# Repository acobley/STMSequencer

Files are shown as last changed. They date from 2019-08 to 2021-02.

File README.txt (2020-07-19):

Production board was :
StmPulse-V1-G49804

*Note* the design has a fault.  R2 and R5 are attached to 5V but should be attached to +5V

I added an airwire to link them on my build.

*NOTE*  the trigger output on board StmPulse-V1-G49804 was only 3.3V whihc is not enough to trigger some modules.

*StmPulse-V2-InProgress.sch*
This fixes the above faults, it connects R2 and R5 to +5V and adds output transistors on the gates to give 5V.

StmPulse-V2-InProgress has *NOT* been built or tested.

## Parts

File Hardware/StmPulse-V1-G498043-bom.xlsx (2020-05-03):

Library | Qty | Parts | Description | Value | Package | LABEL | LABLEL | MPN | Status | OC_FARNELL | OC_NEWARK | PACKAGE | PROD_ID | RS-PART | SF_SKU | SUPPLIER
INSTRUO | 1 | BUT3 |  | PB6149L-5 | PB6149L |  |  |  | y
rcl | 4 | C1, C2, C15, C16 | CAPACITOR, American symbol | 10nF | C0805 |  |  |  | Y 8
rcl | 3 | C3, C5, C8 | CAPACITOR, American symbol | 100n | C0805K |  |  |  | Y
GMSN | 2 | C4, C7 | POLARIZED CAPACITOR, American symbol | 10u | 153CLV-0505 |  |  |  | Y
rcl | 1 | C6 | CAPACITOR, American symbol | 10u | C0805K |  |  |  | Y |  |  |  |  | 737-9704
INSTRUO | 10 | CV1, CV2, CV3, CV4, RESET, START, TRIG1, TRIG2, TRIG3, TRIG4 |  | S_JACK | S_JACK |  |  |  | Y 10
GMSN | 1 | D1 | Diode | Stth102a | SMADIODE |  |  |  | y
Adafruit_1.3_128x64_OLED | 1 | DISPLAY | PIN HEADER |  | MICROBUILDER_1X08_ROUND |  |  |  | Y
GMSN | 1 | IC1 | Positive VOLTAGE REGULATOR | 78M05 | TO252 |  |  |  | Y
GMSN-R2Project | 1 | IC2 | OP AMP | MCP6004D | SO14 |  |  |  | Y
SparkFun-Connectors | 1 | POWER | Multi connection point. Often used as Generic Header-pin footprint for 0.1 inch spaced/style header connections |  | 2X5-SHROUDED_SMD |  |  |  | Y |  |  |  | CONN-09508 | 828-1783
SparkFun-Connectors | 1 | PROGRAM | Multi connection point. Often used as Generic Header-pin footprint for 0.1 inch spaced/style header connections | Program | 1X06 |  |  |  | Y |  |  |  | CONN-08437
rcl | 17 | R1, R2, R3, R4, R5, R6, R7, R8, R9, R10, R11, R12, R15, R18, R21, R22, R24 | RESISTOR, American symbol | 10K | R0805 |  |  |  | n 14 |  |  |  |  | 223-0562 / 125-1189
rcl | 1 | R13 | RESISTOR, American symbol | 2K | R0805 |  |  |  | N |  |  |  |  | 812-3508
rcl | 1 | R14 | RESISTOR, American symbol | 220R | R0805 |  |  |  | Y
rcl | 3 | R16, R19, R23 | RESISTOR, American symbol | 100K | R0805 |  |  |  | Y 8
rcl | 2 | R17, R20 | RESISTOR, American symbol | 1M | R0805 |  |  |  | N |  |  |  |  | 223-0821
GMSN-R2Project | 1 | REF | PRECISION MICROPOWER SHUNT VOLTAGE REFERENCE | LM4040 | SOT95P237X112-3N |  |  | LM4040A30IDBZT | y 1 | 1755108 | 58K5870 | 3-SOT-23 |  | 809-6343 |  | TEXAS INSTRUMENTS
SparkFun-Switches | 2 | S1, S2 | Rotary Encoder w/ Select Switch | ENCODER-SWITCH | ROTARY_ENC_PLAIN |  |  |  | Y 2 |  |  |  |  |  | COM-09117
INSTRUO | 1 | T1_CLOCK |  | 2N3904 | TRANSISTOR_SINGLE_N-TYPE |  | T1_Start |  | y |  |  |  |  | 725-8616
INSTRUO | 1 | T2_RESET |  | TRANSISTOR_MMBT3904 | TRANSISTOR_SINGLE_N-TYPE | T2_Reset |  |  | y |  |  |  |  | 725-8616
BluePill | 1 | U$1 |  | Blue Pill | BLUE_PILL |  |  |  | Y
GMSN-R2Project | 1 | U1 | OP AMP | MCP6004D | SO14 |  |  |  | Y |  |  |  |  | 628-3481 (10)
GMSN-R2Project | 1 | U2-MCP4922 |  | MCP4922MCP4922-SO14 | SO14 |  |  |  | Old |  |  |  |  | 402-910

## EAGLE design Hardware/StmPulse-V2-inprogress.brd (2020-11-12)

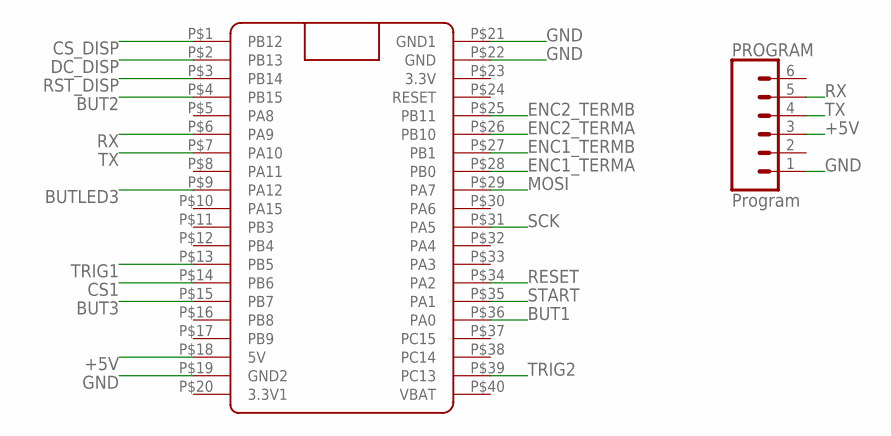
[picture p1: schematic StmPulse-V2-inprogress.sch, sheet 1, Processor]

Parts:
PROGRAM: Program; 1X06
U$1: Blue Pill; BLUE_PILL

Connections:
+5V: PROGRAM.3, U$1.P$18 (5V); also elsewhere on the board
BUT1: U$1.P$36 (PA0); also elsewhere on the board
BUT2: U$1.P$4 (PB15); also elsewhere on the board
BUT3: U$1.P$15 (PB7); also elsewhere on the board
BUTLED3: U$1.P$9 (PA12); also elsewhere on the board
CS1: U$1.P$14 (PB6); also elsewhere on the board
CS_DISP: U$1.P$1 (PB12); also elsewhere on the board
DC_DISP: U$1.P$2 (PB13); also elsewhere on the board
ENC1_TERMA: U$1.P$28 (PB0); also elsewhere on the board
ENC1_TERMB: U$1.P$27 (PB1); also elsewhere on the board
ENC2_TERMA: U$1.P$26 (PB10); also elsewhere on the board
ENC2_TERMB: U$1.P$25 (PB11); also elsewhere on the board
GND: PROGRAM.1, U$1.P$19 (GND2), U$1.P$21 (GND1), U$1.P$22 (GND); also elsewhere on the board
MOSI: U$1.P$29 (PA7); also elsewhere on the board
RESET: U$1.P$34 (PA2); also elsewhere on the board
RST_DISP: U$1.P$3 (PB14); also elsewhere on the board
RX: PROGRAM.5, U$1.P$6 (PA9)
SCK: U$1.P$31 (PA5); also elsewhere on the board
START: U$1.P$35 (PA1); also elsewhere on the board
TRIG1: U$1.P$13 (PB5); also elsewhere on the board
TRIG2: U$1.P$39 (PC13); also elsewhere on the board
TX: PROGRAM.4, U$1.P$7 (PA10)

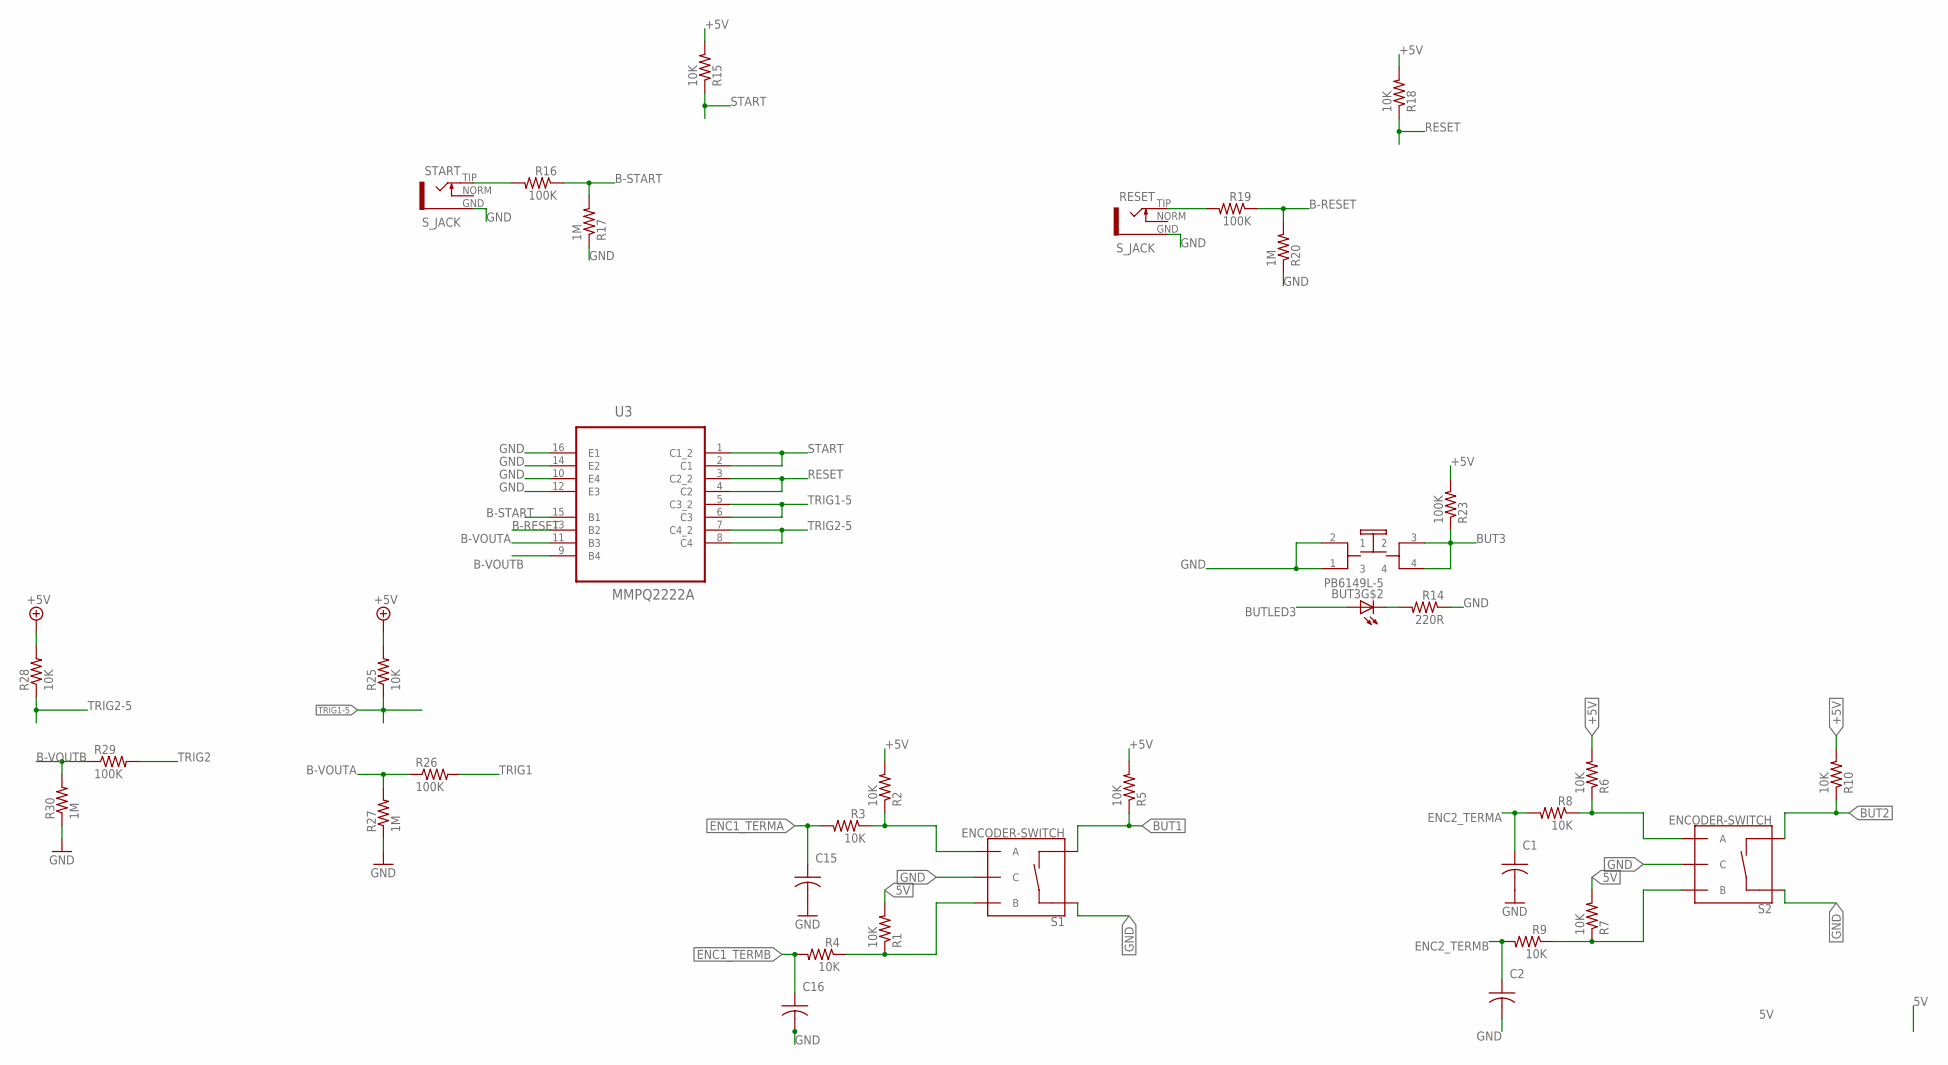
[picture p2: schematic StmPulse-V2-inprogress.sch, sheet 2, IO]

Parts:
BUT3: PB6149L-5; PB6149L
C1, C2, C15, C16: 10nF; C0805
R1, R2, R3, R4, R5, R6, R7, R8, R9, R10, R15, R18, R25, R28: 10K; R0805
R14: 220R; R0805
R16, R19, R23, R26, R29: 100K; R0805
R17, R20, R27, R30: 1M; R0805
RESET: S_JACK
S1, S2: ENCODER-SWITCH; ROTARY_ENC_PLAIN
START: S_JACK
U3: MMPQ2222A; SOIC127P600X175-16N

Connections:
5V: R1.2, R7.2
+5V: R2.2, R5.2, R6.2, R10.2, R15.2, R18.2, R23.2, R25.2, R28.2; also elsewhere on the board
B-RESET: R19.1, R20.2, U3.13 (B2)
B-START: R16.1, R17.2, U3.15 (B1)
B-VOUTA: R26.1, R27.2, U3.11 (B3)
B-VOUTB: R29.1, R30.2, U3.9 (B4)
BUT1: R5.1, S1.SW-; also elsewhere on the board
BUT2: R10.1, S2.SW-; also elsewhere on the board
BUT3: BUT3.3 (2), BUT3.4, R23.1; also elsewhere on the board
BUTLED3: BUT3.A; also elsewhere on the board
ENC1_TERMA: C15.1, R3.2; also elsewhere on the board
ENC1_TERMB: C16.1, R4.2; also elsewhere on the board
ENC2_TERMA: C1.1, R8.2; also elsewhere on the board
ENC2_TERMB: C2.1, R9.2; also elsewhere on the board
GND: BUT3.1 (3), BUT3.2 (1), C1.2, C2.2, C15.2, C16.2, R14.1, R17.1, R20.1, R27.1, R30.1, RESET.GND, S1.C, S1.SW+, S2.C, S2.SW+, START.GND, U3.10 (E4), U3.12 (E3), U3.14 (E2), U3.16 (E1); also elsewhere on the board
unnamed: R6.1, R8.1, S2.A
unnamed: R7.1, R9.1, S2.B
unnamed: R2.1, R3.1, S1.A
unnamed: R1.1, R4.1, S1.B
unnamed: BUT3.K (C), R14.2
unnamed: R19.2, RESET.TIP
unnamed: R16.2, START.TIP
RESET: R18.1, U3.3 (C2_2), U3.4 (C2); also elsewhere on the board
START: R15.1, U3.1 (C1_2), U3.2 (C1); also elsewhere on the board
TRIG1: R26.2; also elsewhere on the board
TRIG1-5: R25.1, U3.5 (C3_2), U3.6 (C3); also elsewhere on the board
TRIG2: R29.2; also elsewhere on the board
TRIG2-5: R28.1, U3.7 (C4_2), U3.8 (C4); also elsewhere on the board

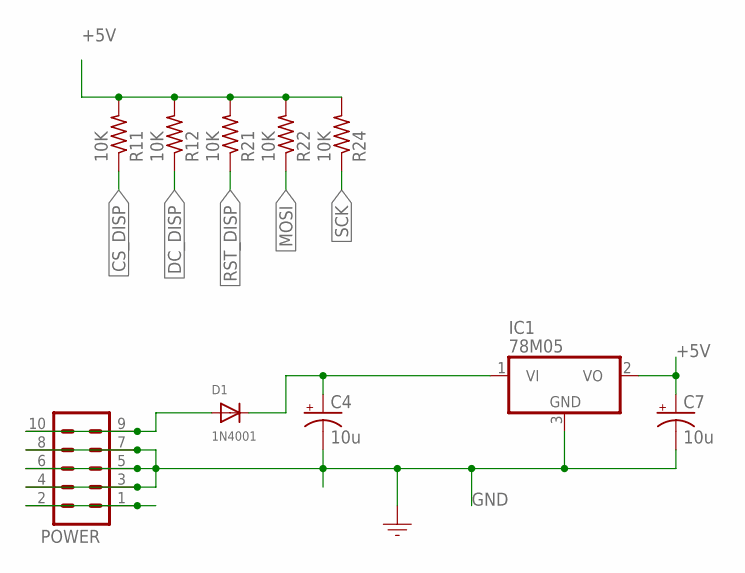
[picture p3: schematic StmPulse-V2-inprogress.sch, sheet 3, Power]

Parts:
C4, C7: 10u; 153CLV-0505
D1: 1N4001; SMADIODE
IC1: 78M05; TO252
POWER: CONN_05X2SHD_SMD; 2X5-SHROUDED_SMD
R11, R12, R21, R22, R24: 10K; R0805

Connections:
+5V: C7.+, IC1.2 (VO), R11.2, R12.2, R21.2, R22.2, R24.2; also elsewhere on the board
+12V: C4.+, D1.C, IC1.1 (VI)
CS_DISP: R11.1; also elsewhere on the board
DC_DISP: R12.1; also elsewhere on the board
GND: C4.-, C7.-, IC1.3 (GND), POWER.3, POWER.4, POWER.5, POWER.6, POWER.7, POWER.8; also elsewhere on the board
MOSI: R22.1; also elsewhere on the board
unnamed: D1.A, POWER.9, POWER.10
unnamed: POWER.1, POWER.2
RST_DISP: R21.1; also elsewhere on the board
SCK: R24.1; also elsewhere on the board

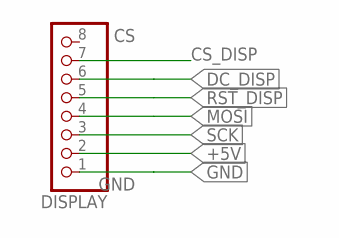
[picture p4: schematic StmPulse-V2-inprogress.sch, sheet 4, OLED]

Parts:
DISPLAY: MICROBUILDER_HEADER-1X8ROUND; MICROBUILDER_1X08_ROUND

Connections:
+5V: DISPLAY.2; also elsewhere on the board
CS_DISP: DISPLAY.7; also elsewhere on the board
DC_DISP: DISPLAY.6; also elsewhere on the board
GND: DISPLAY.1; also elsewhere on the board
MOSI: DISPLAY.4; also elsewhere on the board
RST_DISP: DISPLAY.5; also elsewhere on the board
SCK: DISPLAY.3; also elsewhere on the board

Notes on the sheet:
GND

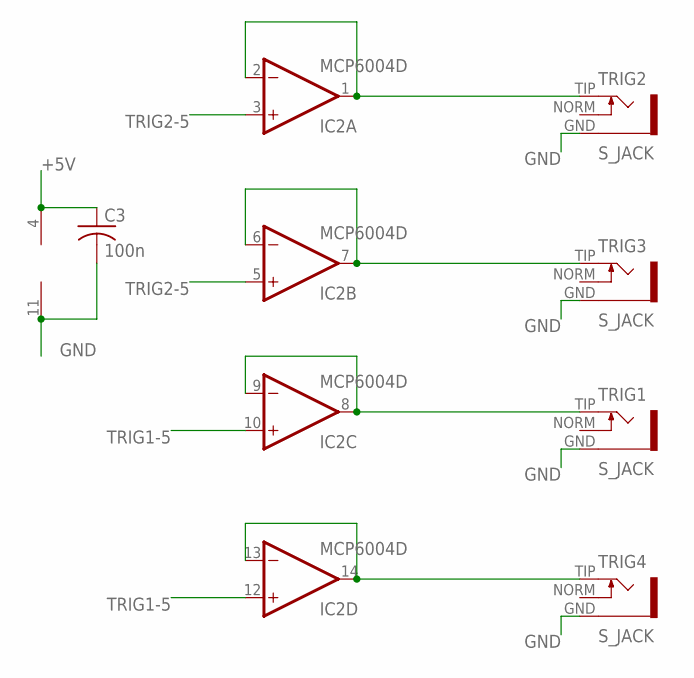
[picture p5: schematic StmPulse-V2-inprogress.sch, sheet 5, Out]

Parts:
C3: 100n; C0805K
IC2: MCP6004D; SO14
TRIG1, TRIG2, TRIG3, TRIG4: S_JACK

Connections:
+5V: C3.1, IC2.4 (V+); also elsewhere on the board
GND: C3.2, IC2.11 (V-), TRIG1.GND, TRIG2.GND, TRIG3.GND, TRIG4.GND; also elsewhere on the board
unnamed: IC2.1 (OUT), IC2.2 (-IN), TRIG2.TIP
unnamed: IC2.8 (OUT), IC2.9 (-IN), TRIG1.TIP
unnamed: IC2.6 (-IN), IC2.7 (OUT), TRIG3.TIP
unnamed: IC2.13 (-IN), IC2.14 (OUT), TRIG4.TIP
TRIG1-5: IC2.10 (+IN), IC2.12 (+IN); also elsewhere on the board
TRIG2-5: IC2.3 (+IN), IC2.5 (+IN); also elsewhere on the board

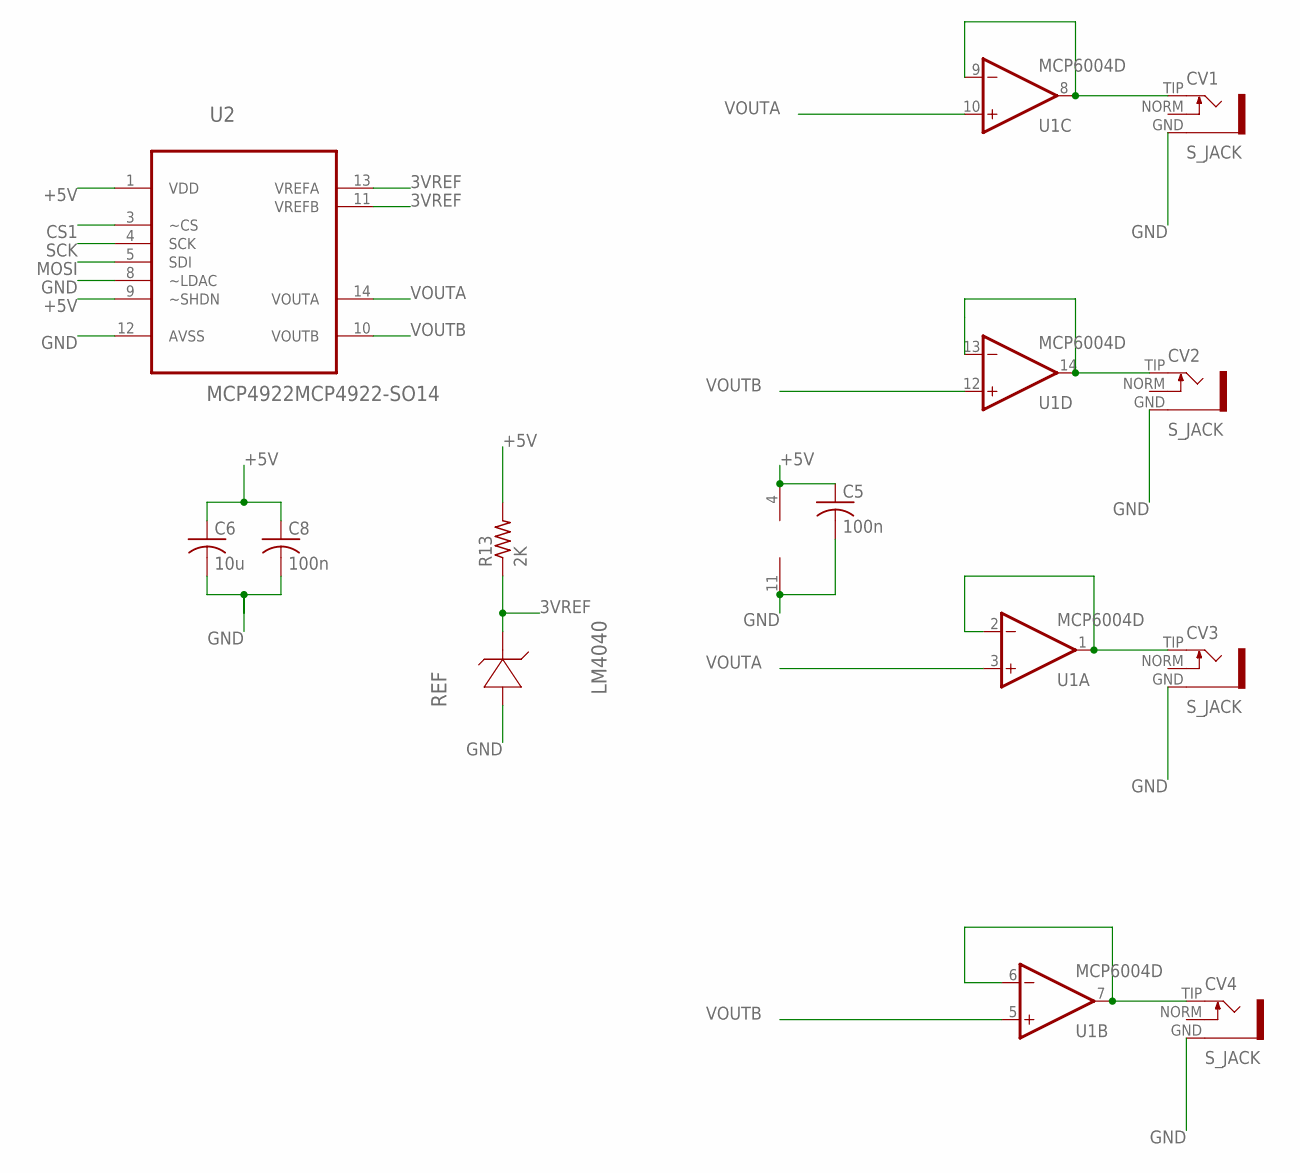
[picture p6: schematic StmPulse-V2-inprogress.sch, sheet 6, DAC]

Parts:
C5, C8: 100n; C0805K
C6: 10u; C0805K
CV1, CV2, CV3, CV4: S_JACK
R13: 2K; R0805
REF: LM4040; SOT95P237X112-3N; MPN LM4040A30IDBZT
U1: MCP6004D; SO14
U2: MCP4922MCP4922-SO14; SO14

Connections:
3VREF: R13.1, REF.1 (CATHODE), U2.11 (VREFB), U2.13 (VREFA)
+5V: C5.1, C6.1, C8.1, R13.2, U1.4 (V+), U2.1 (VDD), U2.9 (~SHDN); also elsewhere on the board
CS1: U2.3 (~CS); also elsewhere on the board
GND: C5.2, C6.2, C8.2, CV1.GND, CV2.GND, CV3.GND, CV4.GND, REF.2 (ANODE), U1.11 (V-), U2.8 (~LDAC), U2.12 (AVSS); also elsewhere on the board
MOSI: U2.5 (SDI); also elsewhere on the board
unnamed: CV3.TIP, U1.1 (OUT), U1.2 (-IN)
unnamed: CV4.TIP, U1.6 (-IN), U1.7 (OUT)
unnamed: CV1.TIP, U1.8 (OUT), U1.9 (-IN)
unnamed: CV2.TIP, U1.13 (-IN), U1.14 (OUT)
SCK: U2.4 (SCK); also elsewhere on the board
VOUTA: U1.3 (+IN), U1.10 (+IN), U2.14 (VOUTA)
VOUTB: U1.5 (+IN), U1.12 (+IN), U2.10 (VOUTB)

Board: 2 copper layers, 68 parts (14 on the bottom side), 50 nets, no tracks yet.

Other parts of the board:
U$2, U$3, U$4, U$5: MOUNTING_HOLE

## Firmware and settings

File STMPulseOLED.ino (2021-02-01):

/*
   Contains code from HobbyComponents.com

   You may copy, alter and reuse this code in any way you like, but please leave
  reference to HobbyComponents.com in your comments if you redistribute this code.
  This software may not be used directly for the purpose of promoting products that
  directly compete with Hobby Components Ltd's own range of products.

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


*/

/*
    To setup BluePill:

    https://circuitdigest.com/microcontroller-projects/getting-started-with-stm32-development-board-stm32f103c8-using-arduino-ide

*/


#include "HardwareTimer.h"
#include "Setup.h"
/*
  void BeatsNumber() {
  float tmp = 0.0;
  int i = 0;
  for (i = 0; i < countlength; i++) {
    if (Timers[i] >= 3) {
      tmp = tmp  + 1.0 / (float)NoteLengths[Timers[i]];
    } else {
      if (Timers[i] == 1) {
        tmp = tmp  + 4;
      } else {
        if (Timers[i] == 2) {
          tmp = tmp  + 2;
        }
      }
    }
  }
  NumberOfBeats = tmp;
  }
*/

void BeatsNumber() {
  float tmp = 0.0;
  int i = 0;
  for (i = 0; i < countlength; i++) {

    tmp = tmp  +  (float)BeatLengths[Timers[i]];

  }
  NumberOfBeats = tmp;
}
#include "Display.h"
#include <EEPROM.h>



short PatternLengths[NumPatterns] = {13, 13, 4, 5, 4, 5, 4};
short NotePatterns [ NumPatterns][MaxPatternLength] = {

  {10, 8, 1, 3, 8, 5, 3, 8, 5, 1, 3, 10, 8},
  {10, 8, 1, 3, 8, 5, 3, 8, 5, 1, 3, 10, 8},
  {3, 3, 10, 1},
  {3, 3, 1, 10, 1},
  {10, 10, 5, 8},
  {10, 10, 8, 5, 8},
  {3, 3, 10, 1},
};
short TimerPatterns [ NumPatterns][MaxPatternLength] = {

  {3, 3, 3, 4, 4, 3, 4, 4, 3, 3, 3, 3, 3},
  {3, 4, 4, 4, 5, 5, 5, 5, 3, 3, 4, 3, 3},
  {3, 3, 3, 3},
  {2, 2, 2, 3, 3},
  {3, 3, 3, 3},
  {2, 2, 2, 3, 3},
  {1, 1, 1, 1},
};
short OctavePatterns [ NumPatterns][MaxPatternLength] = {

  {0, 0, 1, 1, 1, 1, 1, 1, 1, 1, 1, 0, 0},
  {0, 0, 1, 1, 1, 1, 1, 1, 1, 1, 1, 0, 0},
  {1, 1, 2, 2},
  {1, 1, 2, 2, 2},
  {1, 1, 2, 2},
  {1, 1, 2, 2, 2},
  {1, 1, 2, 2},
};
short TripletPatterns[ NumPatterns][MaxPatternLength] = {

  {0, 0, 0, 0, 0, 0, 0, 0, 0, 0, 0, 0, 0},
  {0, 0, 0, 0, 0, 0, 0, 0, 0, 0, 0, 0, 0},
  {0, 0, 0, 0},
  {0, 0, 0, 0, 0},
  {0, 0, 0, 0},
  {0, 0, 0, 0, 0},
  {0, 0, 0, 0},
};

short DottedPatterns[ NumPatterns][MaxPatternLength] = {

  {0, 0, 0, 0, 0, 0, 0, 0, 0, 0, 0, 0, 0},
  {0, 0, 0, 0, 0, 0, 0, 0, 0, 0, 0, 0, 0},
  {0, 0, 0, 0},
  {0, 0, 0, 0, 0},
  {0, 0, 0, 0},
  {0, 0, 0, 0, 0},
  {0, 0, 0, 0},
};

short VolumePatterns[ NumPatterns][MaxPatternLength] = {

  {0, 0, 1, 1, 1, 1, 1, 1, 1, 1, 1, 0, 0},
  {0, 0, 1, 1, 1, 1, 1, 1, 1, 1, 1, 0, 0},
  {1, 1, 1, 1},
  {1, 1, 1, 1, 1},
  {1, 1, 1, 1},
  {1, 1, 1, 1, 1},
  {1, 1, 1, 1},
};



//Low level routines to handle the timers.
//See https://www.st.com/content/ccc/resource/training/technical/product_training/c4/1b/56/83/3a/a1/47/64/STM32L4_WDG_TIMERS_GPTIM.pdf/files/STM32L4_WDG_TIMERS_GPTIM.pdf/j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
//Page 31 and 32

double Div = 1 / 72.0;
double PWM1 = 1;
double PWM2 = 1;
//This one used for Beat Timer
void CalcTCounters( long Time, HardwareTimer myTimer,PWMStruct *PWMS,long Pm1) {

  PWMS->PWM1=Pm1/50;
  PWMS->PWM2=(Time-Pm1)/50;
  DisplayTime(Time,3);
  DisplayTime(Pm1,4);
  DisplayTime(PWMS->PWM1,5);
  DisplayTime(PWMS->PWM2,6);



}

void SetUpTimer(ClockStruct *Clock,HardwareTimer myTimer, voidFuncPtr handler, timer_mode tm) {
  long Time=50L;
  myTimer.pause();
  myTimer.setMode(TIMER_CH1, tm);
  myTimer.attachInterrupt(TIMER_CH1, handler);
  Clock->Psc = 1;
  Clock->Arr = 0;
  Clock->Arr = Time/(Div*Clock->Psc);
  while (Clock->Arr >= 65535) {
    Clock->Psc = Clock->Psc + 1;
    Clock->Arr = Time/(Div*Clock->Psc);

  }
  myTimer.setPrescaleFactor(Clock->Psc);
  myTimer.setOverflow(Clock->Arr-1);
  myTimer.setCompare(TIMER_CH1,Clock->Arr-1);
  myTimer.refresh();

}


void SetupSwitches() {
  pinMode(BUT1, INPUT);
  pinMode(BUT2, INPUT);
  pinMode(STARTBUT, INPUT);
  pinMode(BUTLED3, OUTPUT);
  pinMode(START, INPUT);
  pinMode(RESET, INPUT);
  attachInterrupt(BUT1, iMode2, FALLING);
  attachInterrupt(BUT2, iMode, FALLING);
  attachInterrupt(STARTBUT, StartButtonInterrupt, FALLING);
  attachInterrupt(START, StartInterrupt, RISING);
  attachInterrupt(RESET, IntReset, RISING);

}

void SetupTimers() {
  //These set the timer modes to be correct for accurate timing
  // See http://docs.leaflabs.com/static.leaflabs.com/pub/leaflabs/maple-docs/latest/lang/api/hardwaretimer.html

  //SetUpTimer(SequenceTimer, SequenceGateOn, TIMER_OUTPUT_COMPARE);
  SetUpTimer(&MainClock,MainTimer, MasterClockInterrupt, TIMER_OUTPUT_COMPARE);
  setTempo(Tempo);  //Will also calculate timers.
  BeatPWMS.PWM1Counter=0;
  BeatPWMS.PWM2Counter=0;
  BeatPWMS.Phase=0;
  MainTimer.resume();

}

void MakeActivePattern(short Pattern) {
  int i = 0;
  CurrentPattern = Pattern;
  countlength = PatternLengths[Pattern];
  for (i = 0; i < MaxPatternLength; i++) {
    if (i < PatternLengths[Pattern]) {
      Notes[i] = NotePatterns[Pattern][i];
      Timers[i] = TimerPatterns[Pattern][i];
      Octave[i] = OctavePatterns[Pattern][i];
      Volume[i] = VolumePatterns[Pattern][i];
    }
  }
  CalculateBeatCountArray();
  BeatsNumber();

  DisplayBackground();
  DisplaySeqNum();

  DisplayTempo();
  DisplayMode();
  DisplayMode2();
  DisplayGateLength();


}




void CalculateBeatCountArray() {
  short TimerCount = 0;
  short BeatCount = 1;
  calcBeatPos[0] = 0;
  float CurrentBeatLength = 0;
  int countlength = PatternLengths[CurrentPattern];
  for (TimerCount = 1; TimerCount < countlength; TimerCount++) {

    CurrentBeatLength = CurrentBeatLength + (float)BeatLengths[Timers[TimerCount]];

    if ((CurrentBeatLength == (float)round(CurrentBeatLength))) {
      calcBeatPos[BeatCount] = TimerCount;
      BeatCount++;

    }
  }
  MaxBeat = BeatCount;
  for (int i = 0; i < BeatCount; i++) {
    BeatPos[i] = calcBeatPos[i];
  }
}



void setup() {
  //flash(5);
  SetupOLED();
  ReadEEPROM();
  SetupTimers();
  setTempo(Tempo);
  MakeActivePattern(CurrentPattern);
  SetupEncoders();
  SetupDacs();
  SetupSwitches();
  SetupGates();
  digitalWrite(BUTLED3, false);


}


void loop() {
  handleEnc1();
  handleEnc2();
}

boolean T1State = false;
void MasterClockInterrupt(){
  digitalWrite(Gate1, T1State);
  BeatGate();
  T1State = !T1State;
}

void StartAllTimers() {


  //SequenceGateOn();

}

boolean SequenceState = true;

int lastLength = NoteLengths[Timers[PlaceCount]];
void SequenceGateOn() {
  if (SequenceState == true) {
    digitalWrite(Gate1, true);
    //  Deal with notes
    WriteNote(Notes[PlaceCount], Octave[PlaceCount], CV1);

    // Display count
    DisplayCount(PlaceCount + 1, 0, 0);

    long Time = (long)(BaseTime / NoteLengths[Timers[PlaceCount]]);
    //DisplayCount(NoteLengths[Timers[PlaceCount]], 3,0);
    SeqGateTime = (long)((double)Time * ((double)GateLength / 8.0));
    CalcTCounters(Time, MainTimer,  &SequencePWMS, SeqGateTime);
    lastLength = NoteLengths[Timers[PlaceCount]];

    //Display Cursor

    Cursor(9 * PlaceCount, 12);
    DrawMode(INVERT);
    _WriteChar(BLOCK);

    if (ErasePos >= 0) {

      Cursor(9 * ErasePos, 12);
      DrawMode(INVERT);
      _WriteChar(BLOCK);
    }

    Refresh();
    ErasePos++;
    if (ErasePos >= countlength)
      ErasePos = 0;
    PlaceCount++;
    if (PlaceCount >= countlength) {
      PlaceCount = 0;
      ErasePos = countlength - 1;
      if ((NextPattern >= 0) && (NextPattern < 50)) {
        MakeActivePattern(NextPattern);
        DisplaySeqNum(CurrentPattern);
        NextPattern = -1;
      }
    }
  } else {
    digitalWrite(Gate1, false);

  }
  SequenceState = !SequenceState;
}

boolean BeatState = false;
boolean BeatDispDivisor = false;


void BeatGate(void) {
if (BeatPWMS.Phase==0){ //first phase;
   digitalWrite(BUTLED3, HIGH);
     digitalWrite(Gate2,HIGH);
     BeatPWMS.PWM1Counter++;
     if (BeatPWMS.PWM1Counter>BeatPWMS.PWM1){
        BeatPWMS.Phase=1;
        BeatPWMS.PWM2Counter=1;
        digitalWrite(Gate2,LOW);
     }
  }else{
     digitalWrite(BUTLED3, LOW);
     digitalWrite(Gate2,LOW);
     BeatPWMS.PWM2Counter++;
     if (BeatPWMS.PWM2Counter>BeatPWMS.PWM2){
        BeatPWMS.Phase=0;
        digitalWrite(Gate2,HIGH);
        BeatPWMS.PWM1Counter=1;
     }
  }

/*

  BeatTime = 1000000L * 60 / Tempo;

  if (BeatState == true) {


    digitalWrite(Gate2, HIGH);

    if  (BeatDispDivisor != false) { //The Beat clock runs at 2* for Volcas
      digitalWrite(BUTLED3, HIGH);
      DisplayCount(Beat, 14, 0);
      Cursor(9 * BeatPos[Beat - 1], 16);
      DrawMode(NORMAL);
      _WriteChar('_' - 32);
      bErasePos = Beat - 1;
      if (bErasePos <= 0)
        bErasePos = MaxBeat;
      Cursor(9 * BeatPos[bErasePos - 1], 16);
      DrawMode(CLEAR);
      _WriteChar('_' - 32);
      Refresh();
      Beat++;
      if (Beat > MaxBeat)
        Beat = 1;
    }
    BeatDispDivisor = !BeatDispDivisor;
  } else {
    digitalWrite(Gate2, LOW);

    digitalWrite(BUTLED3, LOW);

  }
  BeatState = !BeatState;

*/

}


boolean Running = false;
unsigned long TempoMicros = micros();
boolean Led = false;
unsigned long micro1 = 1000000;

void StartInterrupt() {
  StartButtonInterrupt();

}

void StartButtonInterrupt() {
  digitalWrite(BUTLED3, !digitalRead(BUTLED3));
  Running = !Running; //invert state

  if (Running) {
    Start();
  } else {
    Stop();
  }

}

void Start() {
  StartAllTimers();
}

void Stop() {
  digitalWrite(Gate1, false); //Avoid stuck notes
  digitalWrite(Gate2, false);
  digitalWrite(BUTLED3, false);
  /*
  SequenceTimer.setCount(0);
  SequenceTimer.pause();
  BeatTimer.setCount(0);
  BeatTimer.pause();
  */
  WriteEEProm();
}

void iMode() {
  Mode++;
  if (Mode > 4) {
    Mode = 0;

  }
  DisplayMode();
}

unsigned long currentMillis = millis();
unsigned long previousMillis = 0;
const long interval = 500;


int SencPos = CurrentPattern;

void iMode2() {
  noInterrupts();
  currentMillis = millis();
  //DisplayTime(currentMillis,previousMillis);
  if (currentMillis - previousMillis >= interval) {
    previousMillis = currentMillis;
    if (Mode2 == 1) {
      NextPattern = SencPos;
      //encPos = TencPos;
      DisplaySeqNum(NewEncPos);
      DisplayTempo();
      Mode2 = 0;

    } else { //From 0 to 1
      //TencPos=encPos;
      SencPos = CurrentPattern;
      Mode2 = 1;
    }
    DisplayMode2();
  }
  interrupts();
}




void handleEnc1() {
  switch (Mode2) {

    case 0:
      NewEncPos = encodeVal(Tempo);
      if (NewEncPos != Tempo) {
        if (NewEncPos < MinTempo) {
          NewEncPos = MinTempo;
        }
        if (NewEncPos > MaxTempo ) {
          NewEncPos = MaxTempo;
        }
        setTempo(NewEncPos);
      }
      break;
    case 1:
      NewEncPos = encodeVal(SencPos);
      if (NewEncPos != SencPos) {
        if (NewEncPos < 1) {
          NewEncPos = 0;
        }
        if (NewEncPos >= NumPatterns ) {
          NewEncPos = NumPatterns - 1;
        }
        DisplaySeqNum(NewEncPos);
        SencPos = NewEncPos; // will be set to next pattern when mode changes
      }
      break;
    default: break;
  }


}

int encodeVal(int val) {
  encAVal = digitalRead(encA);
  encBVal = digitalRead(encB);
  if (encAVal != encALast) {
    if (encAVal == encBVal) {
      val--;
    } else {
      val++;
    }
    encALast = encAVal;

  }
  return val;
}


void IntReset() {
  PlaceCount = 0;
}



void setTempo(int newTempo) {
  Tempo = newTempo;
  BaseTime = 1000000L * (4 * 60) / Tempo;
  BeatTime = 1000000L * 60 / Tempo;
  //DisplayTime (BeatTime );
  CalcTCounters(BeatTime / 2,  MainTimer, &BeatPWMS,(long)15000);
  //CalcTCounters(BaseTime, MainTimer, &SequencePWMS, SeqGateTime);
  DisplayTempo() ;
}



int encodeVal2(int val) {
  encAVal2 = digitalRead(enc2A);
  encBVal2 = digitalRead(enc2B);
  if (encAVal2 != encALast2) {
    if (encAVal2 == encBVal2) {
      val--;
    } else {
      val++;
    }
    encALast2 = encAVal2;

  }
  return val;
}





void handleEnc2() {

  NewEncPos2 = encodeVal2(encPos2);
  if (NewEncPos2 != encPos2) {
    switch (Mode) {
      case 0:
        encPos2 = NewEncPos2;
        if (encPos2 < 1) {
          encPos2 = 1;
        }
        if (encPos2 > 8 ) {
          encPos2 = 8;
        }
        GateLength = encPos2;
        //SeqGateTime = Time * (GateLength / 8);
        //CalcTPeriod(&SequenceClock, BaseTime, SequenceTimer, &SequencePWMS, SeqGateTime);
        DisplayGateLength() ;
        break;
      default: break;
    }
  }
}







void mcpWrite(int value, int Channel) {
  //CS
  noInterrupts();
  digitalWrite(DAC, LOW);
  //DAC1 write
  //set top 4 bits of value integer to data variable
  byte data = value >> 8;
  data = data & B00001111;
  if (Channel == 0)
    data = data | B00110000; //DACA Bit 15 Low
  else
    data = data | B10110000; //DACB Bit 15 High
  SPI.transfer(data);
  data = value;
  SPI.transfer(data);
  // Set digital pin DACCS HIGH
  digitalWrite(DAC, HIGH);
  interrupts();

}

void WriteNote(int Note, int Octave, int Channel) {
  hOctave = Octave;
  hNote = (byte)(Note % 12);
  houtValue = (int)(Range * (hOctave + (float)hNote / 12));
  mcpWrite(houtValue, Channel);

}


void ReadEEPROM() {
  int addr = 0;
  Tempo = EEPROM.read(addr);
  if ((Tempo < 10) || (Tempo > 300))
    Tempo = DefaultTempo;
  setTempo(Tempo);
  addr = addr + 1;
  GateLength = EEPROM.read(addr);
  if (GateLength < 1)
    GateLength = 4;
  if (GateLength > 8)
    GateLength = 4;
  addr = addr + 1;
  CurrentPattern = EEPROM.read(addr);
  if (CurrentPattern < 0)
    CurrentPattern = 2;
  if (CurrentPattern >= NumPatterns)
    CurrentPattern = NumPatterns - 1;
  encPos = Tempo;
  NewEncPos = Tempo;
  encPos2 = GateLength;
  NewEncPos2 = GateLength;
}

void WriteEEProm() {
  int addr = 0;
  EEPROM.write(addr, Tempo);
  addr = addr + 1;
  EEPROM.write(addr, GateLength);
  addr = addr + 1;
  EEPROM.write(addr, CurrentPattern);
}

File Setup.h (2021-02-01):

#include "SPI.h"
#include "fonts.h"


//Encoder
#define encA PB0
#define encB PB1

#define enc2A PB10 //11
#define enc2B PB11 //10
#define BUT1 PA0
#define BUT2 PB15
#define STARTBUT PB7
#define BUTLED3 PA12
#define START PA2
#define RESET PA1

int DAC = PB6; //????
int Gate1 = PB5;
int Gate2 = PC13;
byte CV1 = 1;
byte CV2 = 0;
char Modes[] = {'P', 'L', 'N', 'O', 'M'};
char Modes2[] = {'P', 'S'};
byte Mode = 0;
byte Mode2 = 0;

int encAVal, encALast, encBVal;
int encAVal2, encALast2, encBVal2;

HardwareTimer MainTimer(1);

long ClockF = 72000000;
struct ClockStruct {
  char Name[15];
  long Psc = 0;
  long Arr = 0;
};

struct PWMStruct{
 long PWM1=1;
 long PWM2=1;
 long PWM1Counter=0;
 long PWM2Counter=0;
 boolean Phase=0;
};

ClockStruct MainClock;
PWMStruct BeatPWMS;

PWMStruct SequencePWMS;
ClockStruct SequenceClock;


const short MaxPatternLength = 16;
short Timers[MaxPatternLength] ;
short calcBeatPos[MaxPatternLength];
short BeatPos[MaxPatternLength] ;
short Notes[MaxPatternLength] ;
short Octave[MaxPatternLength] ;
short Volume[MaxPatternLength] ;
int countlength = sizeof(Notes) / sizeof(short);

const short NoteLengths[6] = {0, 1, 2, 4, 8, 16};
const float BeatLengths[6] = {0, 4, 2, 1, 0.5, 0.25};
const short NumPatterns = 7;





const int DefaultTempo=120;
int Tempo = DefaultTempo;
long BaseTime = 1000000L * (4 * 60) / Tempo;
long BeatTime = 1000000L * 60 / Tempo;
short GateLength = 4;
long SeqGateTime = BaseTime * (GateLength / 8);
long ms15 = 015000L;
const short MinTempo = 30;
const short MaxTempo = 300;

int PlaceCount = 0;
int ErasePos = -1;
int bErasePos;
int Beat = 1;
int MaxBeat = 10;

float NumberOfBeats = 1.0;
short CurrentPattern = 0;
short NextPattern = -1;




short encPos = Tempo;
short NewEncPos = Tempo;
short encPos2 = GateLength;
short NewEncPos2 = GateLength;




//float Range = 819.2; // (2^12/5)
float Range = 1365.33333; // (2^12/3)

volatile int hKey ;
volatile int hOctave;
volatile int hNote;
volatile int houtValue;

int CX = 0;
int CY = 0;
int Width = 8;
int Height = 8;


void SetupEncoders() {
  pinMode(encA, INPUT);
  pinMode(encB, INPUT);
  pinMode(enc2A, INPUT);
  pinMode(enc2B, INPUT);

  //digitalWrite(encA, HIGH);
  //digitalWrite(encB, HIGH);
  //digitalWrite(enc2A, HIGH);
  //digitalWrite(enc2B, HIGH);
}


void SetupOLED() {
  _Res_Max_X = SH1106_RES_X;
  _GRAM_Col_Start = SH1106_GRAM_COL_START;
  _GRAM_Col_End = SH1106_GRAM_COL_END;
  _GRAM_Page_Start = SH1106_GRAM_PAGE_START;
  _GRAM_Page_End = SH1106_GRAM_PAGE_END;
  _RAM_Pages = SH1106_GRAM_PAGE_END - SH1106_GRAM_PAGE_START + 1;

  SPI.begin();

  SPI.setBitOrder(MSBFIRST);
  pinMode(CS_DI, OUTPUT);
  pinMode(DC_DI, OUTPUT);
  pinMode(RST_DI, OUTPUT);

  Reset();
  Cursor(0, 0);
  DrawMode(NORMAL);
  _FontType = Terminal_8pt;
  _FontHight = Terminal_8ptFontInfo.CharacterHeight;
  _FontDescriptor = Terminal_8ptFontInfo.Descriptors;
  for (int x = 0; x < 128; x++) {
    for (int y = 0; y < 64; y++) {
      Plot(x, y);
    }
    Refresh();
  }

  DrawMode(CLEAR);
  for (int x = 0; x < 128; x++) {
    for (int y = 0; y < 64; y++) {
      Plot(x, y);
    }
    Refresh();
  }

  Erase(0, 0, 128, 64);
  Refresh();

}

void SetupDacs() {
  SPI.begin();
  SPI.setBitOrder(MSBFIRST);
  pinMode(DAC, OUTPUT);

  digitalWrite(DAC, HIGH);

}



void SetupGates() {
  pinMode(Gate2, OUTPUT);
  pinMode(Gate1, OUTPUT);
}

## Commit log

2019-05-28 updated Timer to use HardwareTimer timer(1);
2019-05-28 updated Timer to refresh
2019-06-07 added switch interupt
2019-06-11 added encoder2
2019-06-17 Added Hardware
    [StmPulse-V1-InProgress.brd, StmPulse-V1-InProgress.sch]
2019-06-18 moved mounting holes
    [StmPulse-V1-InProgress.brd]
2019-06-22 Changed C and R to 805
    [StmPulse-V1-InProgress.brd, StmPulse-V1-InProgress.sch]
2019-08-11 Updated encoder switches
    [StmPulse-V1-InProgress.brd, StmPulse-V1-InProgress.sch]
2019-08-11 updated hardware
    [StmPulse-V1-InProgress.brd, StmPulse-V1-InProgress.sch]
2020-01-13 V1 Board Ordered
    [StmPulse-V1-G498043.brd, StmPulse-V1-G498043.sch]
2020-01-13 gerfiles for V1
    [StmPulse-V1-InProgress.GBL, StmPulse-V1-InProgress.GBO, StmPulse-V1-InProgress.GBP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]
2020-05-02 Added BOM
    [StmPulse-V1-G498043-bom.csv, StmPulse-V1-G498043-bom.xlsx]
2020-05-03 updated BOM and RS component
    [StmPulse-V1-G498043-bom.xlsx, StmPulse-V1-G498043.brd, StmPulse-V1-G498043.sch]
2020-05-10 Changed calibration to 3V
2020-07-19 Added note about trigger voltage
2020-11-12 added V2 hardware, fixing wiring fault
    [StmPulse-V2-inprogress.brd, StmPulse-V2-inprogress.sch]
2020-11-15 Fixed thempo jump on pattern change
    [STMPulseOLED.ino, Setup.h]
2020-11-19 fixed hole and half notes
    [STMPulseOLED.ino]

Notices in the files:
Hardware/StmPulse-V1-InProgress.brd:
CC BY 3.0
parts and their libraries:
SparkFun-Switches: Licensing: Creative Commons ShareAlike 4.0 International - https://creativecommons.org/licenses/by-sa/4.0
